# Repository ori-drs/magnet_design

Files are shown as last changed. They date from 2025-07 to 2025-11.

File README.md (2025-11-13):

# magnet_design
Design instructions for the ORI Magnet Lidar Mapping device

<p align="center">
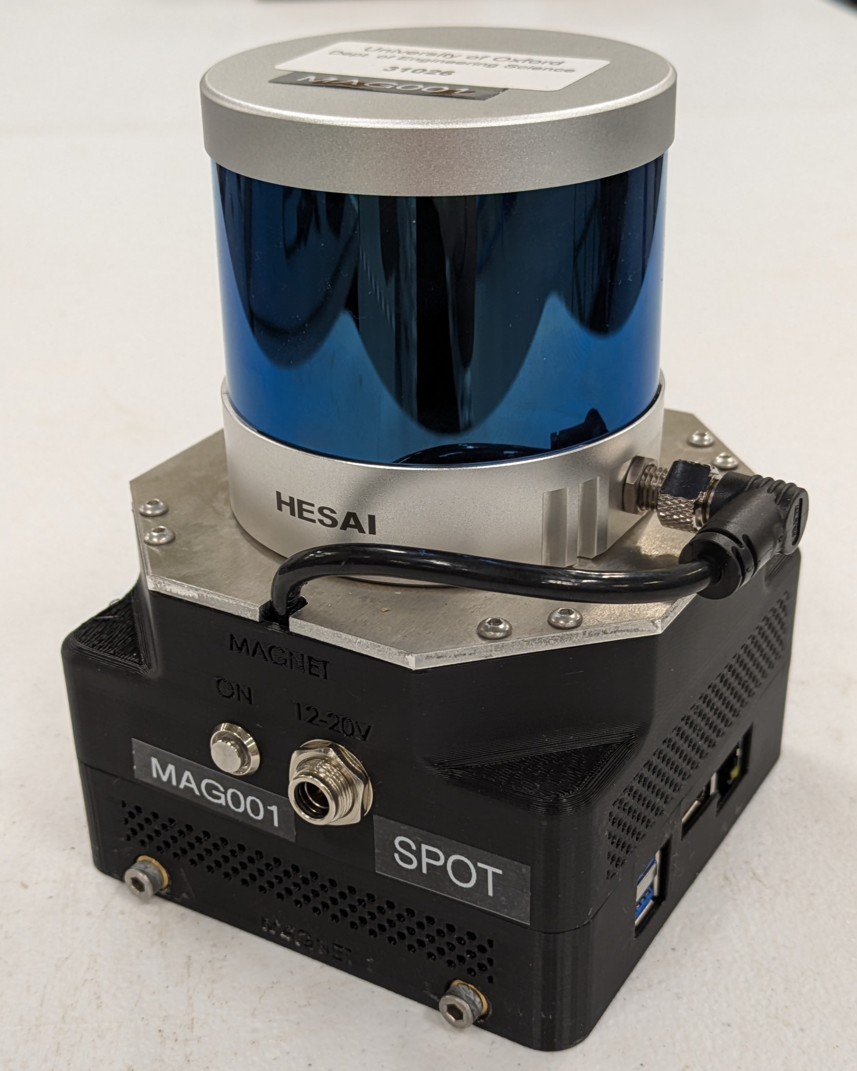
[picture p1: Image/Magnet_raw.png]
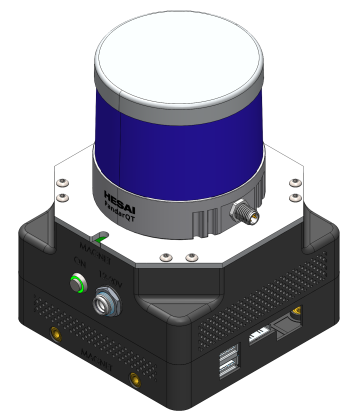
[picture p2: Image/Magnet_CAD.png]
   
</p>

Magnet is a compact, rugged LiDAR mapping unit developed at the Oxford Robotics Institute (ORI) for research into 3D mapping and mobile robot autonomy. It integrates a Hesai QT64 LiDAR, a Microstrain GX5-15 IMU, and an Intel NUC computer, all housed within a modular enclosure. The device is capable of running real-time 3D mapping algorithms and can be mounted on a robot or used as a handheld device.

This repository provides the 3D CAD files and basic manufacturing guidance required to reproduce the hardware. Note that Magnet requires additional software to perform 3D mapping or enable autonomy in robotic applications.

## Core Components

| Component | Model |
|---|---|
| Onboard Computer | [Intel NUC Topaz 3 i7](https://simplynuc.co.uk/product/nuc13tzi7/) |
| IMU | [Microstrain 3DM-GX5-AR](https://www.hbkworld.com/en/products/transducers/inertial-sensors/vertical-reference-units--vru-/3dm-gx5-ar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)|
| LiDAR | [HESAI QT64](https://www.datrontechnology.co.uk/qt64/)|

## Mechanical Design & CAD
This repository contains the STEP files for the CAD models and the corresponding STL files for 3D printing.

- **Overall size and weight:** 110 × 110 × 148 mm (including QT64), 1106 g
- **Design files directory:** [`CAD/Magnet`](./CAD/Magnet)
- **URDF link:** [`magnet_description`](https://github.com/ori-drs/magnet_description)

## Assembly Notes

<p align="center">
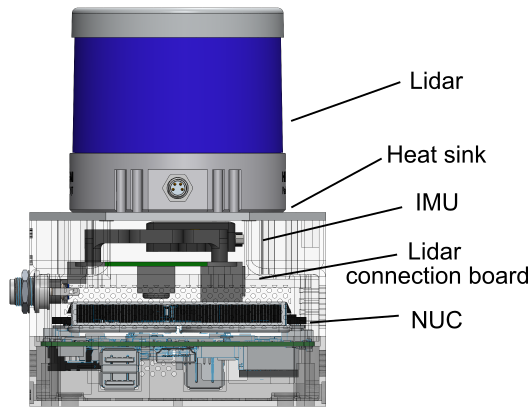
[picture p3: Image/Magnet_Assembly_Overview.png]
  
</p>

- **Case:** 3D printed in PLA using a Bambu Lab printer.  
- **Heatsink:** Cut from a 3 mm aluminium sheet.  
  *Note: A metal sheet is highly recommended to ensure effective heat dissipation during prolonged LiDAR operation*

- **Tappex inserts (for 3D printed parts):**
  - **Top case:** 16 × M3 × 5.2 mm (unflanged)
  - **Bottom case:** 8 × M4 × 3.0 × 7.9 mm (flanged)  
    *These inserts are used to mount Magnet onto robots or rigs.*
  - **IMU mount:** 2 × M3 × 5.2 mm (unflanged)
- **Power inlet:** 2.5mm DC Socket (e.g. L712AS)
- **Wiring logic:**
  <p align="center">
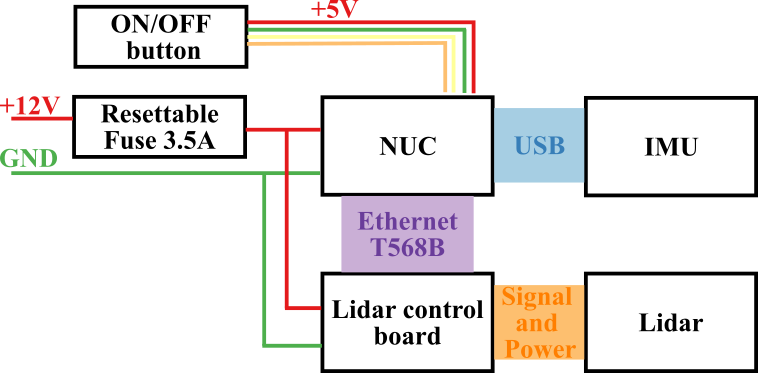
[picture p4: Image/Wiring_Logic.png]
     
  </p>
   
  *Note: This is not a schematic diagram. For detailed electronic connections, please refer to the datasheets of the respective components.*

## Power supply
- **Input voltage:** 12–19 V  
- **Maximum power:** 90 W    
  *Note: These values are specific to our physical prototype and may vary depending on the components used in your build.*

## Application Example - Wearable Mobile Device
Magnet can be configured as a portable mapping unit for field data collection. In this setup, the device is mounted on a mounting pole and powered by an external battery pack. This design allows handheld or backpack-based operation for large-scale 3D environment mapping. 
<p align="center">
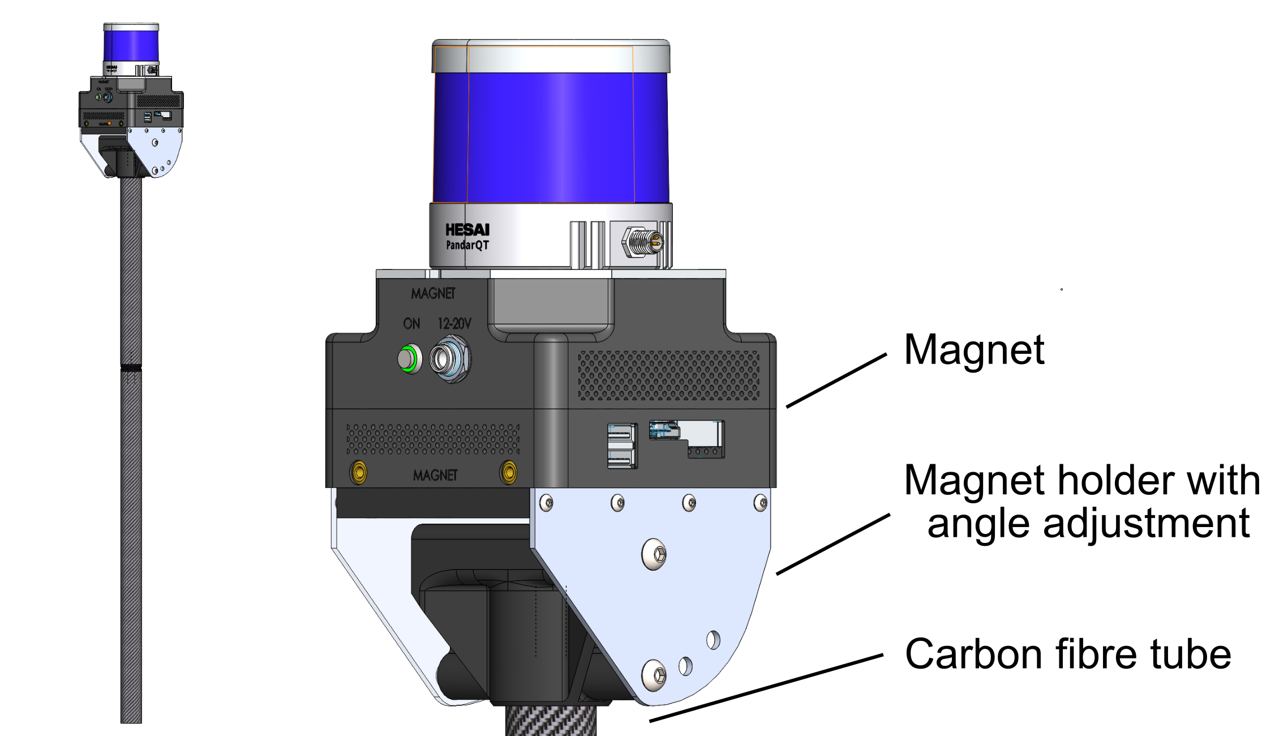
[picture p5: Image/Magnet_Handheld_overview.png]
  
</p>
The current wearable configuration developed at ORI consists of:

- **Mounting pole:** 80 cm carbon fibre tube (Ø 30 mm) and a 3D printed Magnet holder with an angle adjustment mechanism
- **Total height:** 85 cm (pole only) / 100 cm (including Magnet)  
- **System weight:** ≈ 4 kg (including backpack frame, pole, Magnet, and battery)  
- **Energy source:** PAG 90 Slim Battery - 90Wh 14.8V nominal 
- **Design files directory:** [`CAD/Mounting_Pole`](./CAD/Mounting_Pole) with manufacturing notes in [`CAD/Mounting_Pole/Manufacturing_note`](./CAD/Mounting_Pole/Manufacturing_note.md)

The Magnet can be attached to the mounting pole using four M4 screws to secure the unit's Tappex mounting points (on the bottom case) to the dedicated holder interface.
<p align="left">
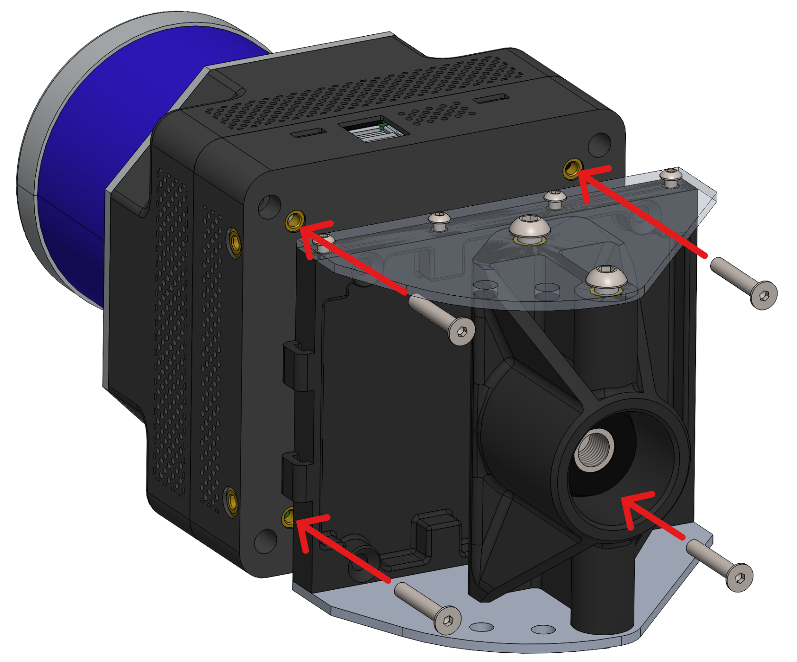
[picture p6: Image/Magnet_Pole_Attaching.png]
   
</p>  
This assembled Magnet-pole can then be mounted onto a backpack with an aluminium support frame for extended deployment or mapping missions.
<p align="left">
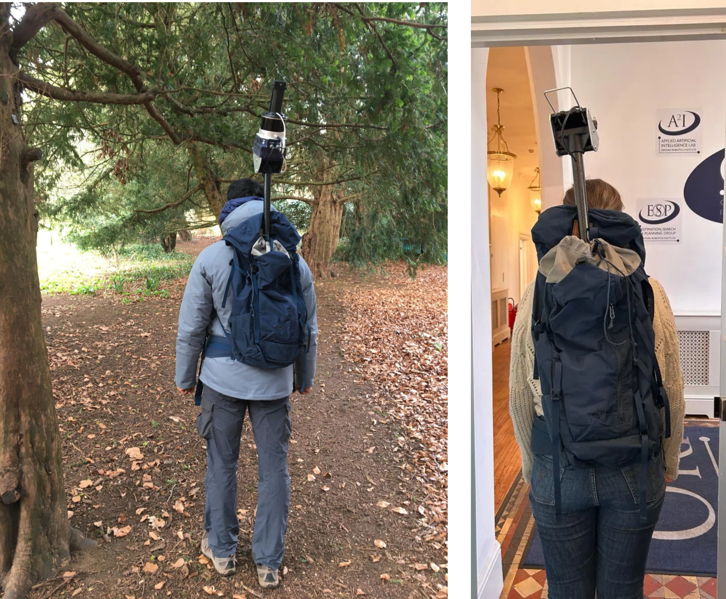
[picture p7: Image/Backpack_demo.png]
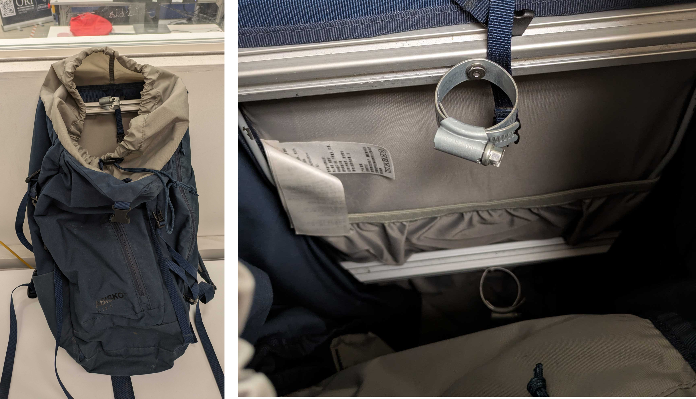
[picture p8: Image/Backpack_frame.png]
   
</p>  

## Application Example - Robot Deployment
Magnet can be integrated into a robotic platform for autonomous mapping and navigation. The device can be mounted securely using the Tappex mounting points (located on the side and bottom of the Magnet case) to a dedicated holder interface (not included in this repository and subjected to individual platform) on the robot. At ORI, Magnet has been successfully deployed on the Clearpath Jackal robot, where it is powered from the robot’s onboard supply via a bulk regulator. 
<p align="left">
  
</p>  

*Note: It is important to ensure that the electrical specifications of the target platform are compatible with Magnet’s requirements, or else an appropriate regulator or power management module must be added.*

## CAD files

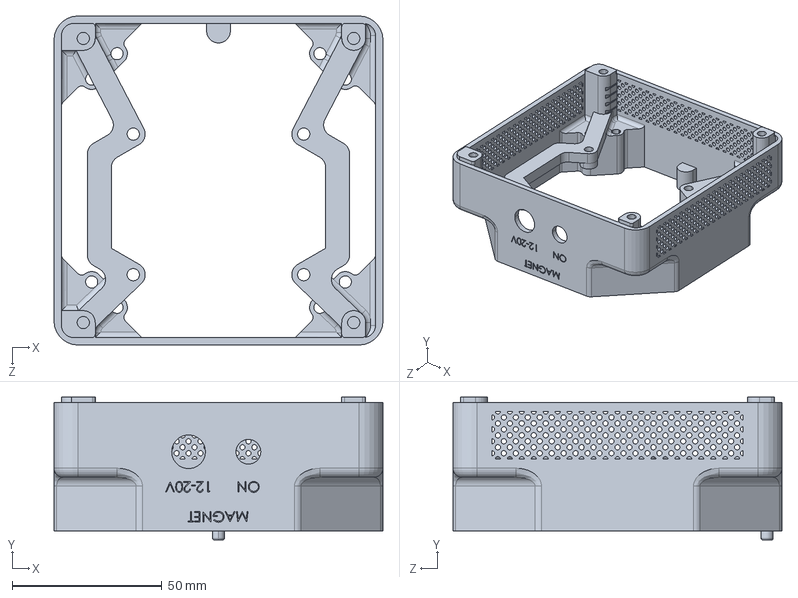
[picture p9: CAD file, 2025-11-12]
CAD/Magnet/STEP/Magnet - Casing - Top.STEP
110.0 x 47.8 x 110.0 mm

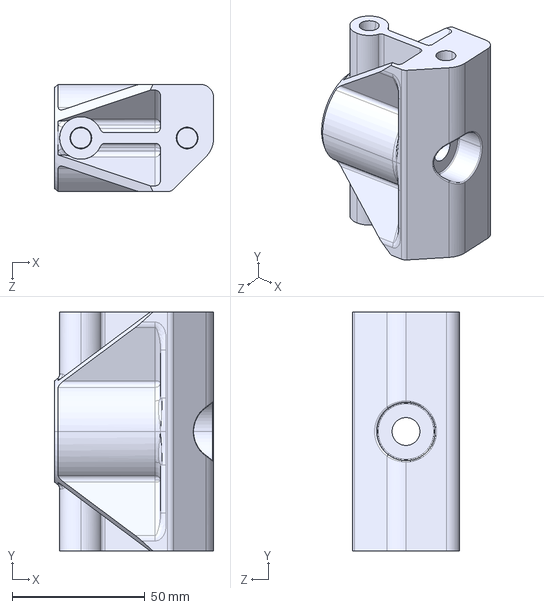
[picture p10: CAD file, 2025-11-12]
CAD/Mounting_Pole/STEP/Mast_Cap.STEP
60.0 x 90.0 x 40.4 mm

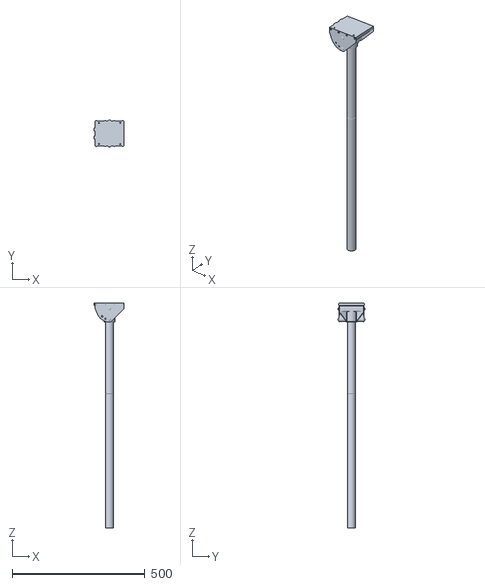
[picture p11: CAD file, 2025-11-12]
CAD/Mounting_Pole/STL/Magnet_mounting_pole_model.STL
114.5 x 101.6 x 847.0

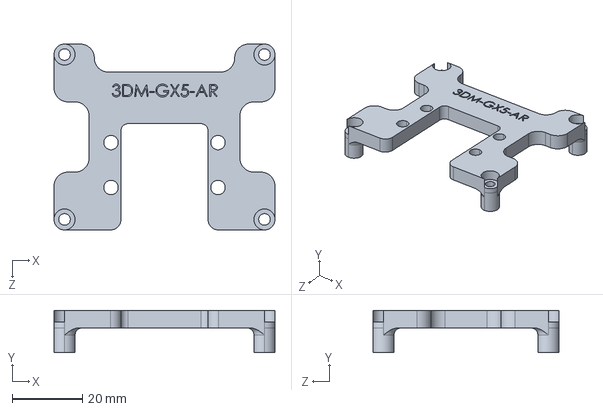
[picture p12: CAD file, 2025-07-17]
CAD/Magnet/STEP/3DM-GX5-AR Adapter.STEP
63.0 x 12.0 x 53.0 mm

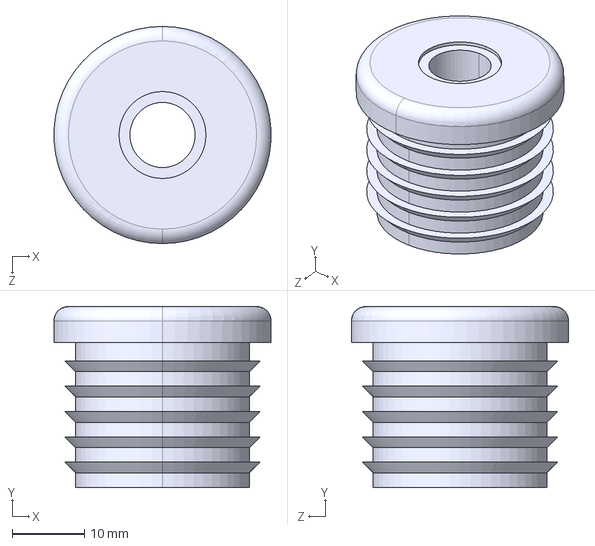
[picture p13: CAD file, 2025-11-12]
CAD/Mounting_Pole/STEP/CF_Tube_Insert.STEP
30.0 x 25.0 x 30.0 mm

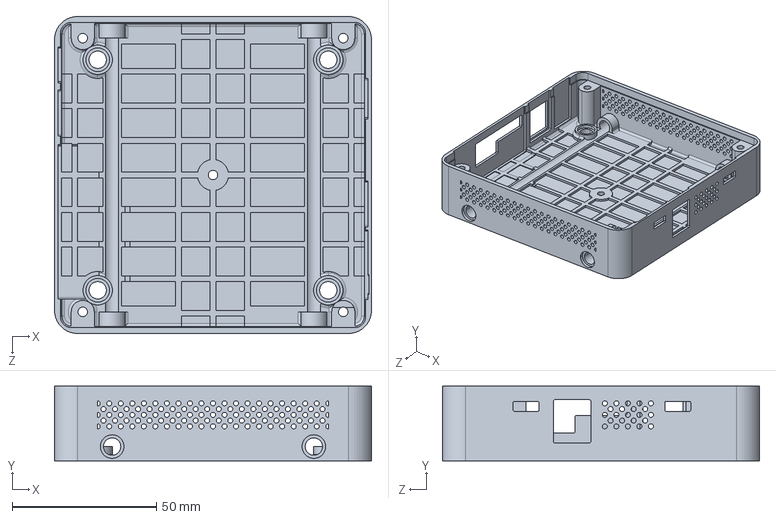
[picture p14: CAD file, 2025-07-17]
CAD/Magnet/STEP/Magnet - Casing - Bottom.STEP
110.0 x 26.0 x 110.0 mm

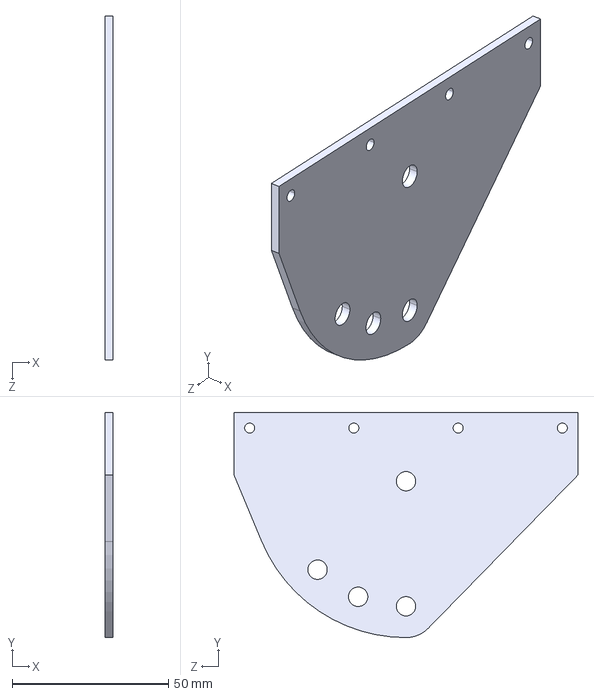
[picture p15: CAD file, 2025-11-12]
CAD/Mounting_Pole/STEP/Tilt_Side_Panel.STEP
2.50 x 72.0 x 110.0 mm

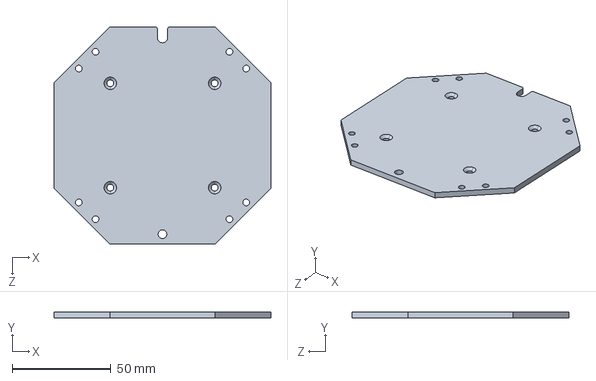
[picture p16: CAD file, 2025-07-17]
CAD/Magnet/STEP/Heatsink.STEP
110.0 x 3.00 x 110.0 mm

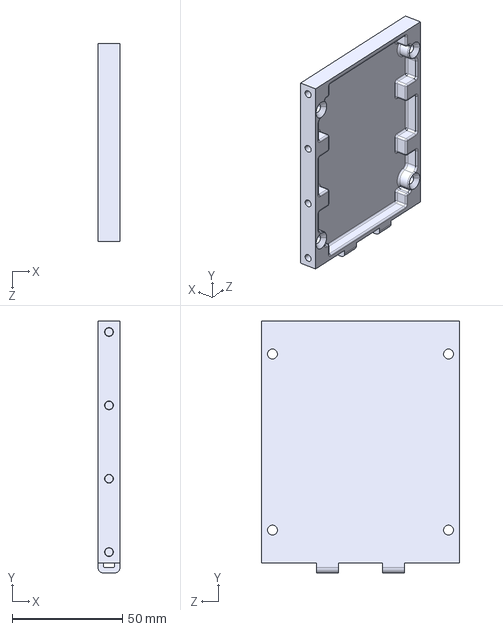
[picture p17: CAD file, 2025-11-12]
CAD/Mounting_Pole/STEP/Magnet_mounting_plate.STEP
10.0 x 114.5 x 90.0 mm

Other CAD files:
CAD/Magnet/STL/3DM-GX5-AR Adapter.STL
CAD/Magnet/STL/Heatsink.STL
CAD/Magnet/STL/Magnet - Casing - Bottom.STL
CAD/Magnet/STL/Magnet - Casing - Top.STL
CAD/Mounting_Pole/STL/Magnet_mounting_plate.STL
CAD/Mounting_Pole/STL/Mast_Cap.STL
CAD/Mounting_Pole/STL/Tilt_Side_Panel.STL

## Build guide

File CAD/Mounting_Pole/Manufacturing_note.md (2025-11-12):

# magnet_mounting_pole_manufacturing_note
Manufacturing notes for the ORI Magnet Mounting Pole

<p align="center">
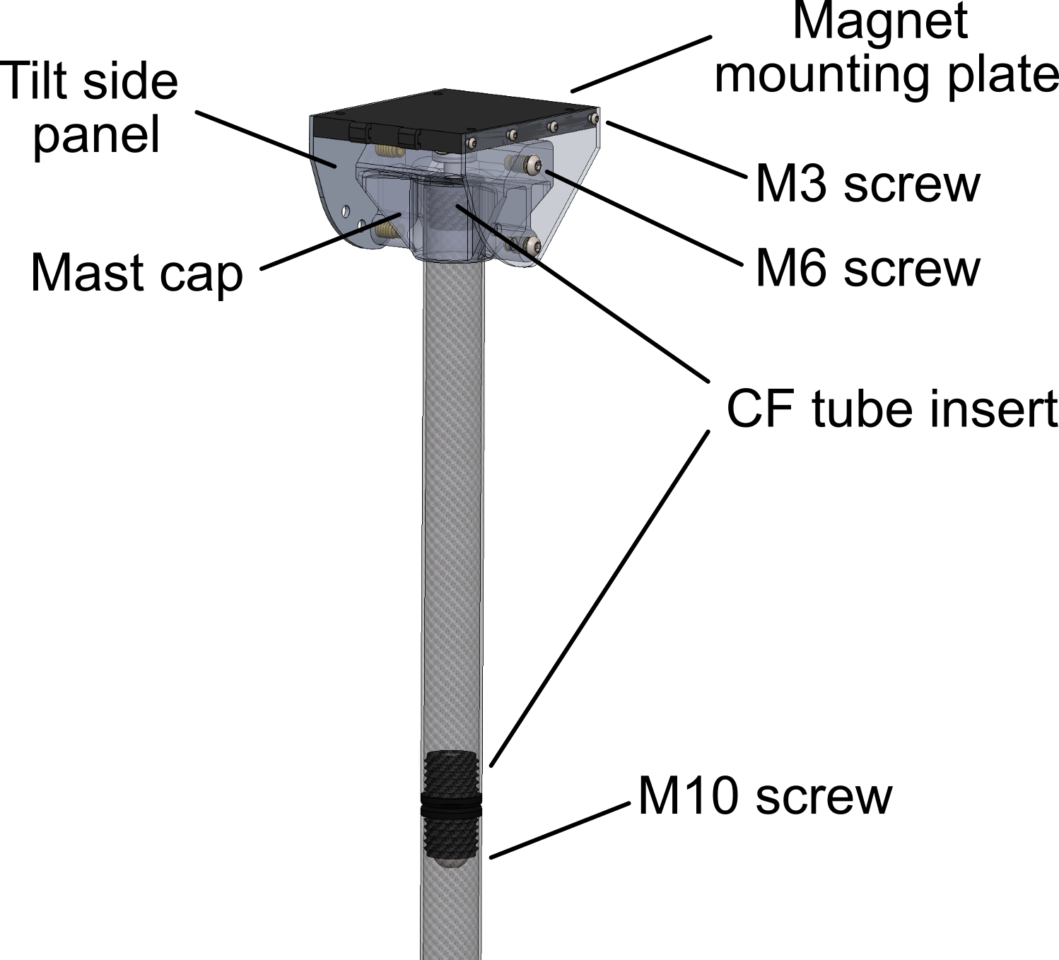
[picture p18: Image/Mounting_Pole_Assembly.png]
  
</p>

This document provides technical guidance for manufacturing the Magnet mounting pole used in field data collection with the ORI Magnet LiDAR mapping device.  
The pole assembly consists of two sections: the Magnet holder and the pole body.

## 1. Magnet Holder

The Magnet holder is a modular structure designed to secure the Magnet unit and allow adjustable orientation. It consists of the following components:

- **Magnet mounting plate:** The primary platform for securing the Magnet using M4 screws at the Tappex mounting points.  
- **Tilt side panel:** Provides the angle adjustment mechanism and additional structural support between the mounting plate and the mast cap.  
- **Mast cap:** Connects the holder assembly to the carbon fibre pole via a threaded insert.

*Notes*
*- These component should be 3D-printed in a material (e.g., PLA or PETG) with at least 30% infill for strength.*
*- The tilt adjustment mechanism is recommanded to be manufactured from an aluminium plate via CNC machining for rigidity*

## 2. Pole Body

The pole body is made from a carbon fibre (CF) tube with an outer diameter of 30 mm.  
The inner diameter and wall thickness are not critical, as long as the tube maintains adequate structural integrity.

- The length of the CF tube can be adjusted depending on the application.  
- In the current ORI design, the CF tube includes a [CF insert with an M10 internal thread](https://www.accu.co.uk/metal-threaded-inserts-standard/588069-HMTIR-30-M10-HDPE-BL), which connects the mast cap for modular assembly and additional CF tube segments using M10 screws for extension.

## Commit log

2025-07-17 Update README.md
    Add photos of the Magnet and it with Jackal
2025-11-12 Update the readme, included the mounting pole CAD and manufacturing insturction
    [3DM-GX5-AR Adapter.STEP, 3DM-GX5-AR Adapter.STL, CF_Tube_Insert.STEP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]
2025-11-12 update the readme and mounting_pole_manufacturing_note
